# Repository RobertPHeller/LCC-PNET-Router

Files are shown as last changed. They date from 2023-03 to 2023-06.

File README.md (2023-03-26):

# LCC-PNET-Router

This is a "router" between a LCC network and a Pricom Lighting PNET network.
It translates between LCC event reports and PNET Trigger, Control, and Dimmer 
messages.  The PCB contains CAN transceivers for the two CAN IFs on a 
PocketBeagle, with one wired to LCC network connectors (RJ45s) and the other 
wired for PNET (RJ12 6-6).  The "firmware" compiles and runs on a 32-bit ARM
Linux SBC (tested on a Beagle Bone using GridConnect over Tcp/Ip for the LCC
network and the Virtual CAN driver (vcan) for the PNET network.

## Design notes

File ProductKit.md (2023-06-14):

This is a "router" between a LCC network and a Pricom Lighting PNET network.
It translates between LCC event reports and PNET Trigger, Control, and Dimmer 
messages.  The PCB contains CAN transceivers for the two CAN IFs on a 
PocketBeagle, with one wired to LCC network connectors (RJ45s) and the other 
wired for PNET (RJ12 6-6).  Both networks have data activity LEDs and an 
on-board termination jumper header.  And the LCC network has power injection
and tap screw terminals.

This kit contains:

- The PCB with all of the SMD parts assembled.
- The through-hole parts (to be soldered on by the end user):
    - 2 RJ45 8-8 connectors
    - 2 RJ12 6-6 connectors
    - 2 2.54mm (.1") screw terminal blocks
    - 2 2x18 2.54mm (.1") pitch socket headers
    - 1 2x40 2.54mm (.1") pitch "breakaway" pin headers
    - 1 USB A connector
- 1 MicroSD card containing the firmware image
- 4 2.54mm (.1") shorting jumpers (for the termination headers)
 
Not included: a [PocketBeagle](https://duckduckgo.com/?t=ffab&q=pocketBeagle&iax=shopping&ia=shopping).

The included firmware is built to provide 32 each of PNET controls, triggers,
and dimmers.  Each PNET message item maps two LCC events to the PNET message,
one eventid is consumed to generate the PNET message and the other is produced
when the matching PNET message is seen on the PNET network.  The PNET message
processing is configured using the LCC CDI configuration (eg with JMRI's 
PanelPro or DWS's OpenLCB program).

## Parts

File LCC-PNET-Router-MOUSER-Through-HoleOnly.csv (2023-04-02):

Item | Qty | Reference(s) | Value | LibPart | Footprint | Datasheet | Mouser Part Number
1 | 1 | J101 | USB_A | conn:USB_A | USB-A-Upright:USB-A-UPRIGHT |  | 710-614004184726
2 | 2 | J202, J203 | RJ45 | conn:RJ45 | RJ45-8N-S:RJ45_8N-S |  | 710-615008144221
3 | 2 | J302, J303 | PNET | conn:RJ12 | RJ12Molex:95501-2661 |  | 538-95501-2661
4 | 2 | P1, P2 | POCKETBEAGLE-P2 | pocketbeagle:POCKETBEAGLE-P2 | Socket_Strips:Socket_Strip_Straight_2x18_Pitch2.54mm |  | 517-929975-01-18-RK
5 | 1 |  | Pin Headers |  | Socket_Strips:Pin_Strip_Straight_2x40_Pitch2.54mm |  | 710-61308021121
6 | 2 | T201, T202 | LCC Power In/Out | conn:Screw_Terminal_01x02 | Connectors_Terminal_Blocks:TerminalBlock_Pheonix_MPT-2.54mm_2pol |  | 651-1703144

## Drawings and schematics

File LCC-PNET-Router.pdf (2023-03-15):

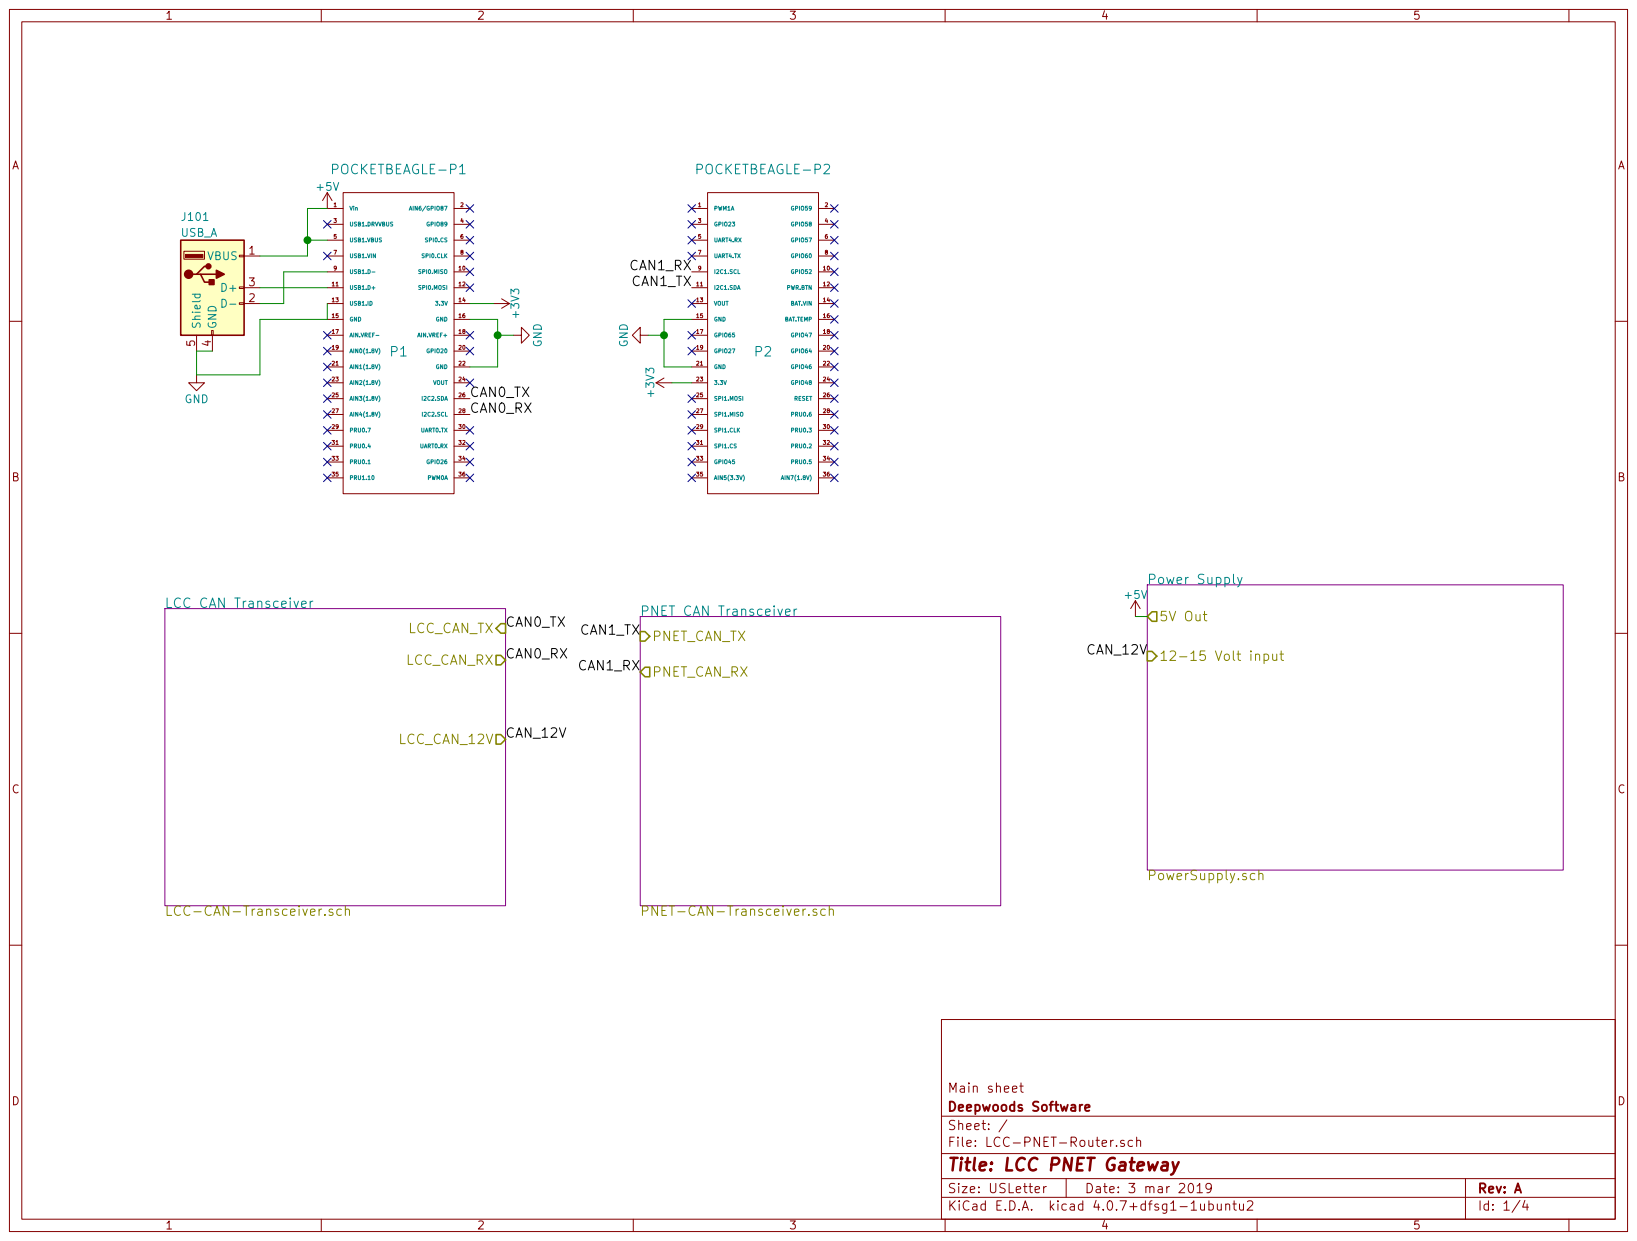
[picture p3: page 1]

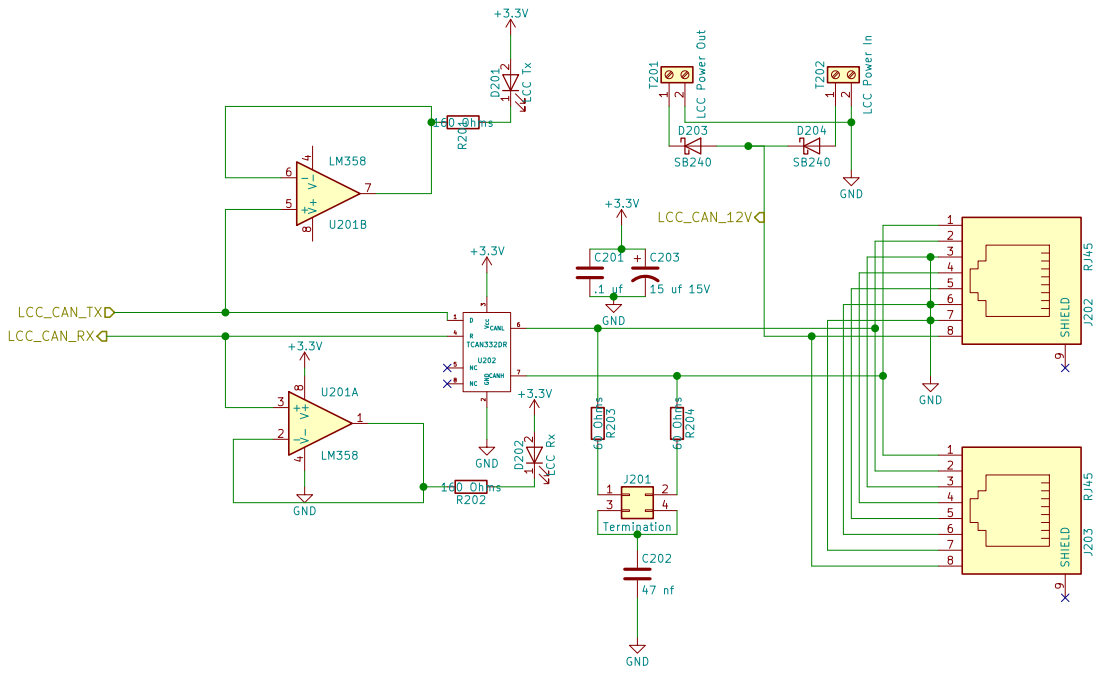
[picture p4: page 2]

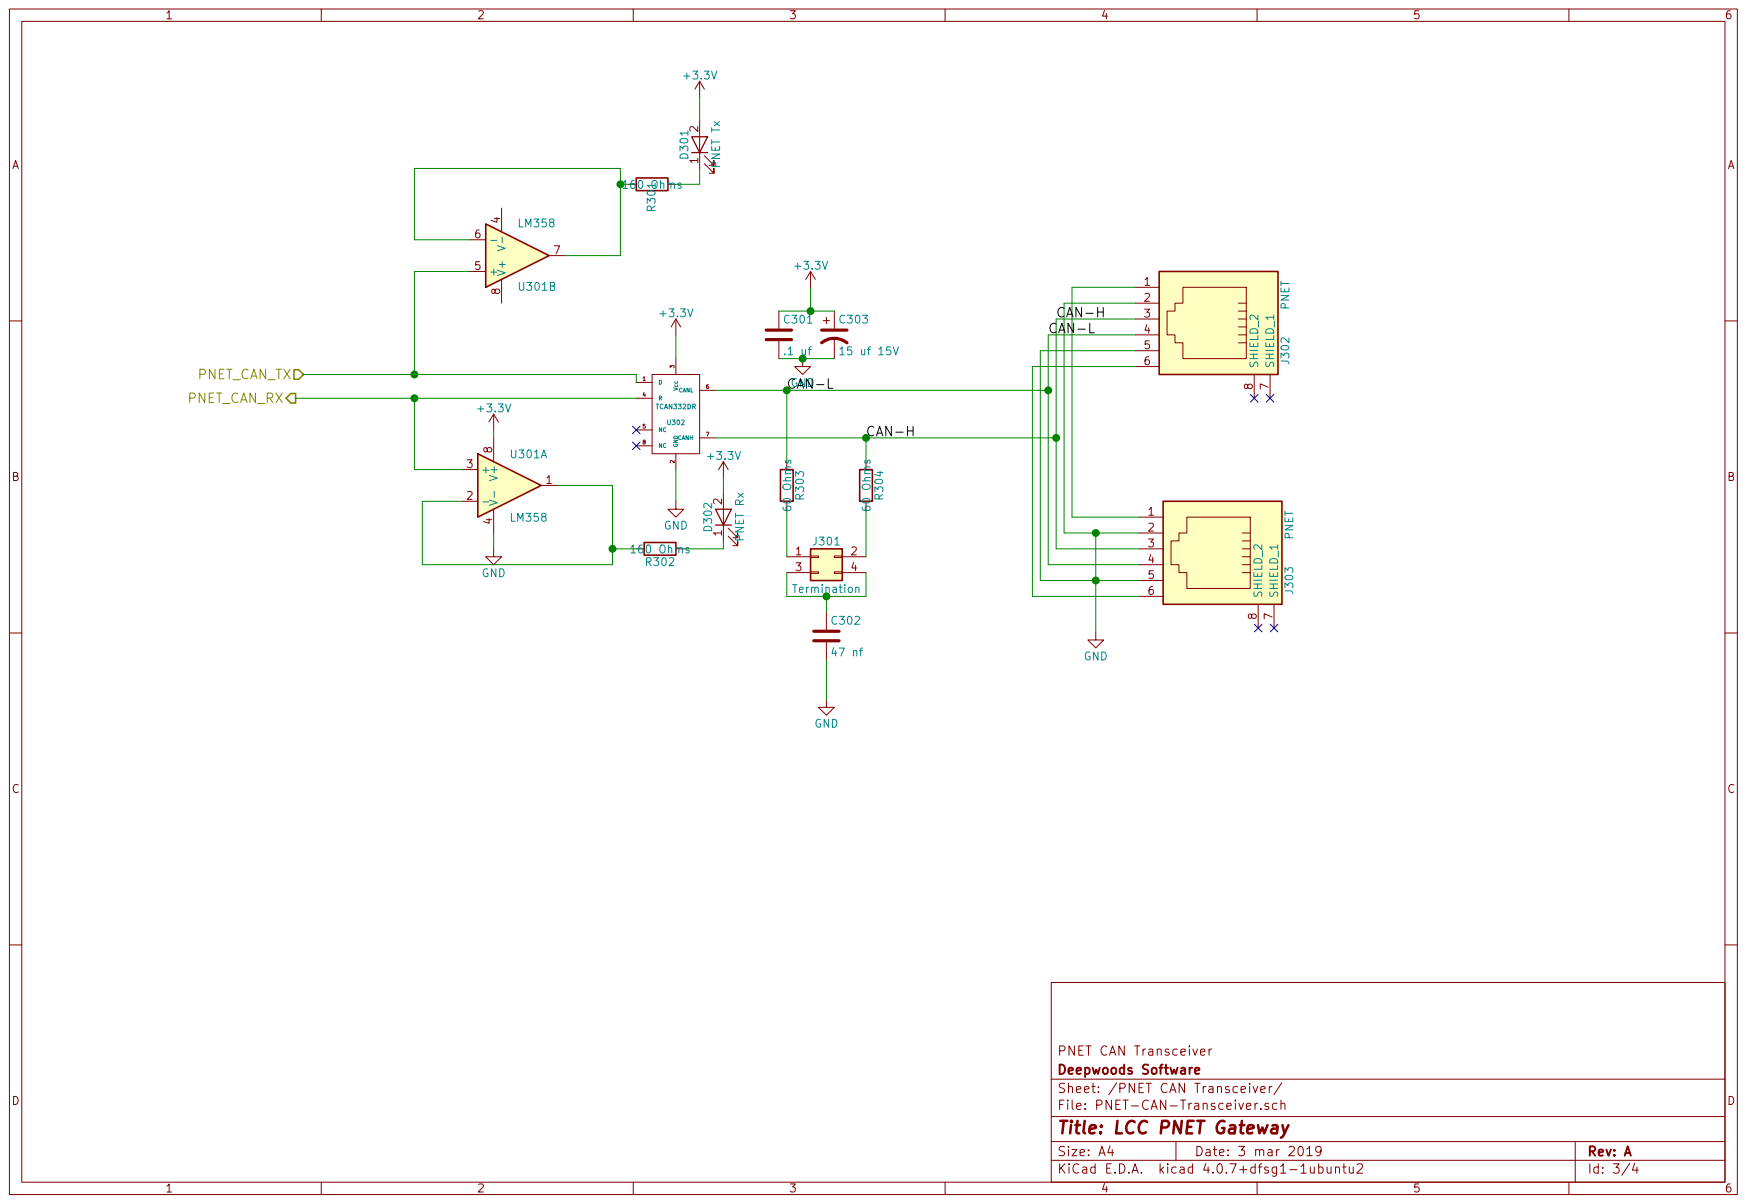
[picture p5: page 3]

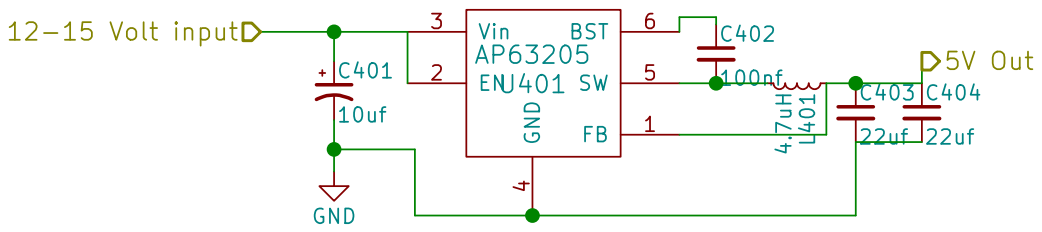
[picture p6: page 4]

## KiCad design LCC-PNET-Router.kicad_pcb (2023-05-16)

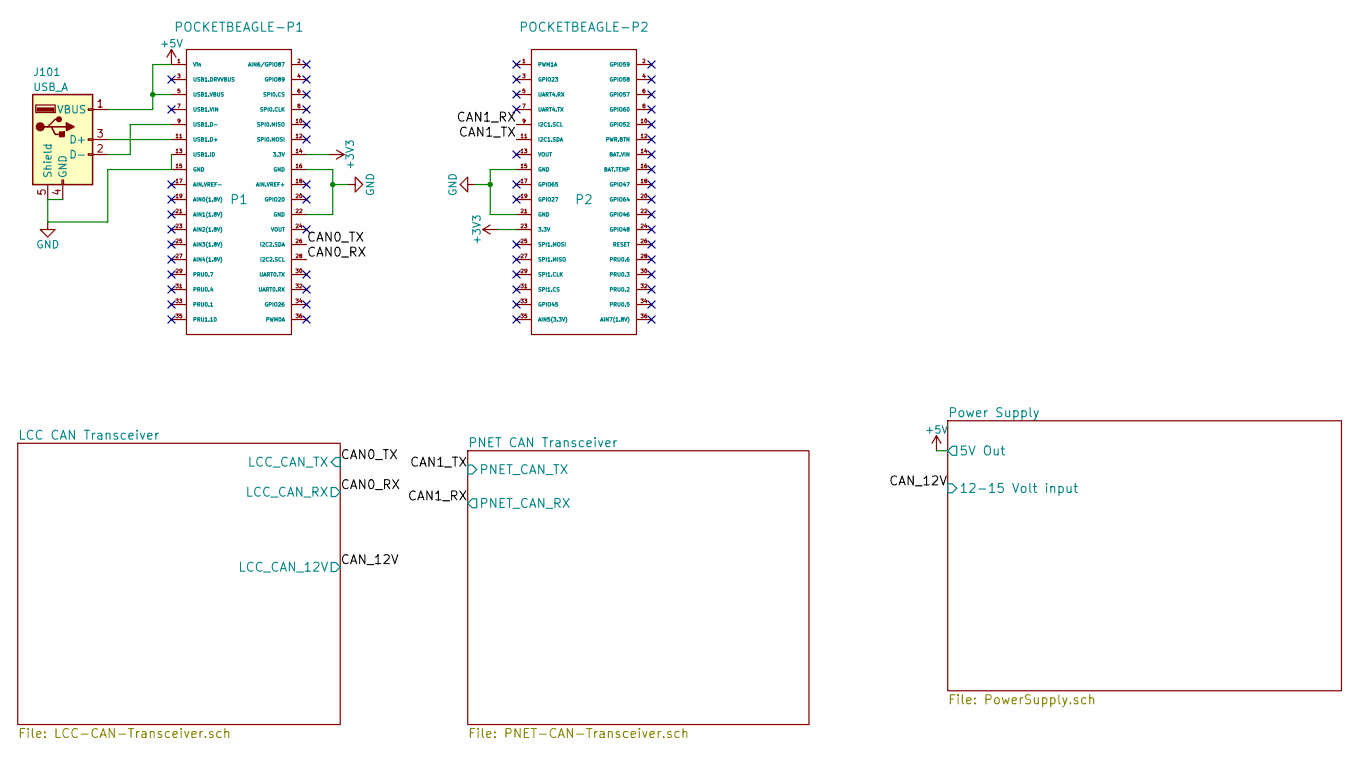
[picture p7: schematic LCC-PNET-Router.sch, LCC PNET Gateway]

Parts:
J101: USB_A; USB-A-UPRIGHT; Mouser Part Number 710-614004184726
P1: POCKETBEAGLE-P1; Socket_Strip_Straight_2x18_Pitch2.54mm; Mouser Part Number 517-929975-01-18-RK
P2: POCKETBEAGLE-P2; Socket_Strip_Straight_2x18_Pitch2.54mm; Mouser Part Number 517-929975-01-18-RK

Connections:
+5V: J101.1 (VBUS), P1.1 (Vin), P1.5 (USB1.VBUS); also elsewhere on the board
/CAN0_RX: P1.28 (I2C2.SCL); also elsewhere on the board
/CAN0_TX: P1.26 (I2C2.SDA); also elsewhere on the board
/CAN1_RX: P2.9 (I2C1.SCL); also elsewhere on the board
/CAN1_TX: P2.11 (I2C1.SDA); also elsewhere on the board
GND: J101.4 (GND), J101.5 (Shield), P1.13 (USB1.ID), P1.15 (GND), P1.16 (GND), P1.22 (GND), P2.15 (GND), P2.21 (GND); also elsewhere on the board
unnamed: J101.2 (D-), P1.9 (USB1.D-)
unnamed: J101.3 (D+), P1.11 (USB1.D+)

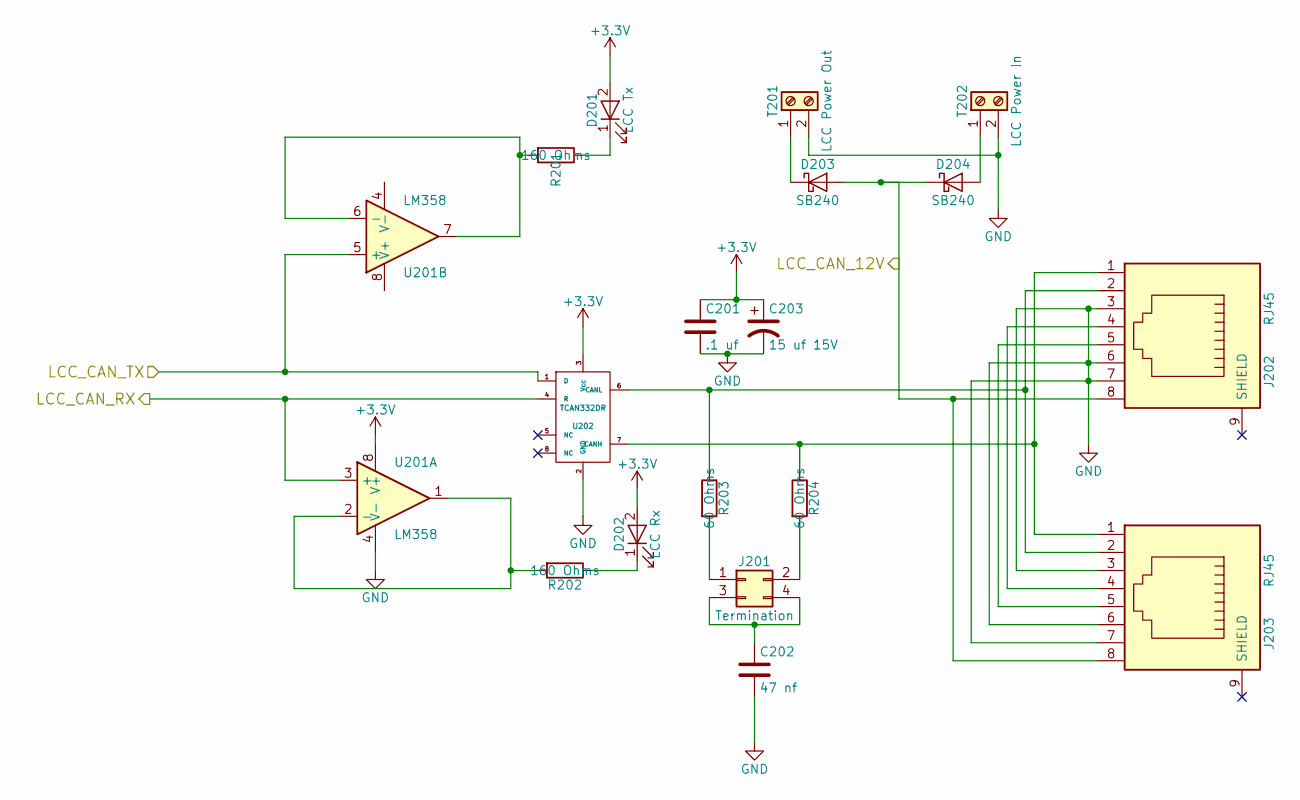
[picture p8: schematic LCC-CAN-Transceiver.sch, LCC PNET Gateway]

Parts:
C201: .1 uf; C_0603; Mouser Part Number 603-CC603KPX7R9BB104
C202: 47 nf; C_0603; Mouser Part Number 963-GMK107BJ473KAHT
C203: 15 uf 15V; CP_Elec_4x5.8; Mouser Part Number 647-UUD1C150MCL
D201: LCC Tx; LED_0603; Mouser Part Number 710-150060SS75000
D202: LCC Rx; LED_0603; Mouser Part Number 710-150060YS75000
D203, D204: SB240; D_PowerDI-123; Mouser Part Number 621-DFLS240-7
J201: Termination; Pin_Header_Straight_2x02_Pitch2.54mm; Mouser Part Number 649-1012938190402BLF
J202, J203: RJ45; RJ45_8N-S; Mouser Part Number 710-615008144221
R201, R202: 160 Ohms; R_0603; Mouser Part Number 603-AC0603JR-07160RL
R203, R204: 60 Ohms; R_1206; Mouser Part Number 71-CRCW120660R0KNAIF
T201: LCC Power Out; TerminalBlock_Pheonix_MPT-2.54mm_2pol; Mouser Part Number 651-1725656
T202: LCC Power In; TerminalBlock_Pheonix_MPT-2.54mm_2pol; Mouser Part Number 651-1725656
U201: LM358; SOIC-8_3.9x4.9mm_Pitch1.27mm; Mouser Part Number 595-LM358DR
U202: TCAN332DR; SOIC-8_3.9x4.9mm_Pitch1.27mm; Mouser Part Number 595-TCAN332DR

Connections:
/CAN0_RX: U201.3 (+), U202.4 (R); also elsewhere on the board
/CAN0_TX: U201.5 (+), U202.1 (D); also elsewhere on the board
/CAN_12V: D203.2 (A), D204.1 (K), J202.8, J203.8; also elsewhere on the board
GND: C201.2, C202.2, C203.2, J202.3, J202.6, J202.7, J203.3, J203.6, J203.7, T201.2, T202.2, U201.4 (V-), U202.2 (GND); also elsewhere on the board
unnamed: C202.1, J201.3, J201.4
unnamed: D201.1 (K), R201.1
unnamed: D202.1 (K), R202.1
unnamed: D203.1 (K), T201.1
unnamed: D204.2 (A), T202.1
unnamed: J201.1, R203.2
unnamed: J201.2, R204.2
unnamed: J202.1, J203.1, R204.1, U202.7 (CANH)
unnamed: J202.2, J203.2, R203.1, U202.6 (CANL)
unnamed: J202.4, J203.4
unnamed: J202.5, J203.5
unnamed: R201.2, U201.6 (-), U201.7
unnamed: R202.2, U201.1, U201.2 (-)

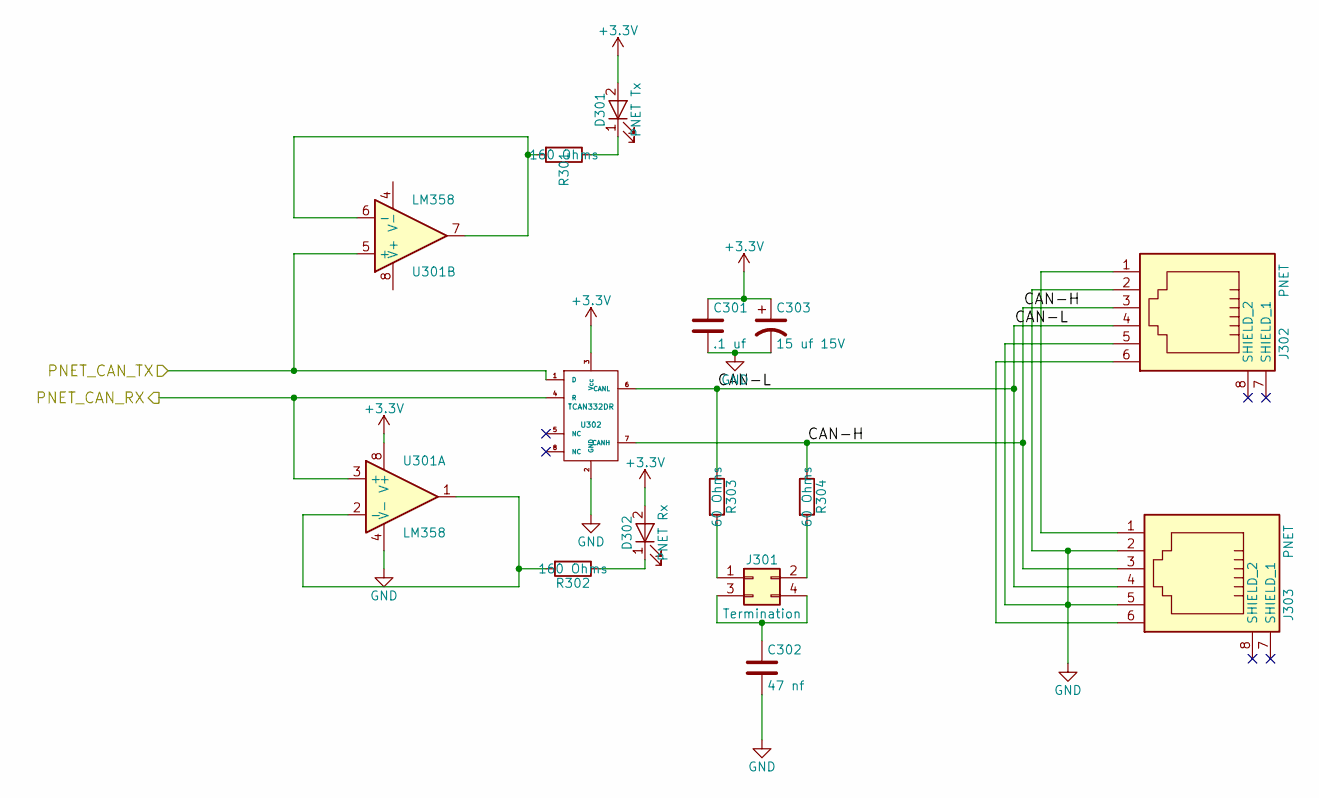
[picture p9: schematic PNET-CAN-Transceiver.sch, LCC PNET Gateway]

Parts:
C301: .1 uf; C_0603; Mouser Part Number 603-CC603KPX7R9BB104
C302: 47 nf; C_0603; Mouser Part Number 963-GMK107BJ473KAHT
C303: 15 uf 15V; CP_Elec_4x5.8; Mouser Part Number 647-UUD1C150MCL
D301: PNET Tx; LED_0603; Mouser Part Number 710-150060SS75000
D302: PNET Rx; LED_0603; Mouser Part Number 710-150060YS75000
J301: Termination; Pin_Header_Straight_2x02_Pitch2.54mm; Mouser Part Number 649-1012938190402BLF
J302, J303: PNET; 95501-2661; Mouser Part Number 538-95501-2661
R301, R302: 160 Ohms; R_0603; Mouser Part Number 603-AC0603JR-07160RL
R303, R304: 60 Ohms; R_1206; Mouser Part Number 71-CRCW120660R0KNAIF
U301: LM358; SOIC-8_3.9x4.9mm_Pitch1.27mm; Mouser Part Number 595-LM358DR
U302: TCAN332DR; SOIC-8_3.9x4.9mm_Pitch1.27mm; Mouser Part Number 595-TCAN332DR

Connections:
/CAN1_RX: U301.3 (+), U302.4 (R); also elsewhere on the board
/CAN1_TX: U301.5 (+), U302.1 (D); also elsewhere on the board
/PNET CAN Transceiver/CAN-H: J302.3, J303.3, R304.1, U302.7 (CANH)
/PNET CAN Transceiver/CAN-L: J302.4, J303.4, R303.1, U302.6 (CANL)
GND: C301.2, C302.2, C303.2, J302.2, J302.5, J303.2, J303.5, U301.4 (V-), U302.2 (GND); also elsewhere on the board
unnamed: C302.1, J301.3, J301.4
unnamed: D301.1 (K), R301.1
unnamed: D302.1 (K), R302.1
unnamed: J301.1, R303.2
unnamed: J301.2, R304.2
unnamed: J302.1, J303.1
unnamed: J302.6, J303.6
unnamed: R301.2, U301.6 (-), U301.7
unnamed: R302.2, U301.1, U301.2 (-)

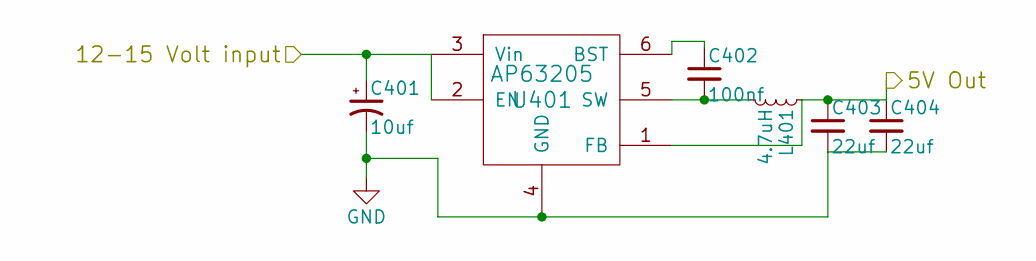
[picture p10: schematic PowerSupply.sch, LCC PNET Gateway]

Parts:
C401: 10uf; CP_Elec_5x5.3; Mouser Part Number 710-865230542002
C402: 100nf; C_0603; Mouser Part Number 710-885012206020
C403, C404: 22uf; C_0603; Mouser Part Number 81-GRM188R60G226ME0J
L401: 4.7uH; L_7.3x7.3_H4.5; Mouser Part Number 81-B1047AS-4R7NP3
U401: AP63205; TSOT-23-6_MK06A; Mouser Part Number 621-AP63205WU-7

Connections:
+5V: C403.1, C404.1, L401.1, U401.1 (FB); also elsewhere on the board
/CAN_12V: C401.1, U401.2 (EN), U401.3 (Vin); also elsewhere on the board
GND: C401.2, C403.2, C404.2, U401.4 (GND); also elsewhere on the board
unnamed: C402.1, U401.6 (BST)
unnamed: C402.2, L401.2, U401.5 (SW)

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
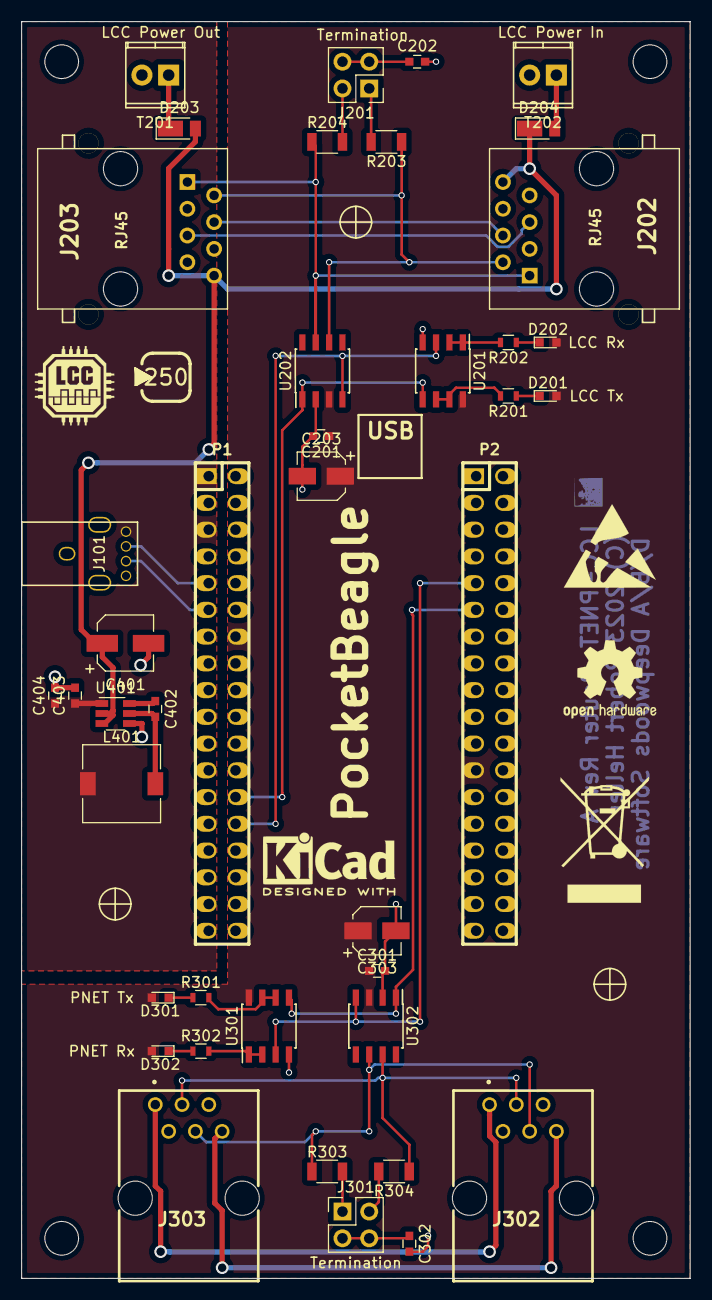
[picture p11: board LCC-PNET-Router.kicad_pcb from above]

Board: 2 copper layers, 63.5 x 119.4 mm, 41 parts (0 on the bottom side), 36 nets.

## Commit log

2023-01-12 Start on LCC <=> PNET router.
    [LCC-CAN-Transceiver.sch, LCC-PNET-Router.kicad_pcb, LCC-PNET-Router.sch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]
2023-01-12 Start on PCB layout.
    [LCC-PNET-Router.kicad_pcb, LCC-PNET-Router.sch, PowerSupply.sch]
2023-03-15 Completed initial HW design.
    [LCC-CAN-Transceiver.sch, LCC-PNET-Router.kicad_pcb, LCC-PNET-Router.sch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]
2023-03-15 Add Schematic PDF.
    [LCC-CAN-Transceiver.sch, LCC-PNET-Router.sch, PNET-CAN-Transceiver.sch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]
2023-03-15 Correct for CAN Polarity on the PNET connectors.
    [LCC-PNET-Router.kicad_pcb, PNET-CAN-Transceiver.sch]
2023-03-18 Refactor PNETTriggerService using an iterator flow.
2023-03-22 Update RJ12 Jacks.
    [LCC-PNET-Router.kicad_pcb, PNET-CAN-Transceiver.sch]
2023-03-22 Complete 3D and final touches on PCB.
    [LCC-PNET-Router.kicad_pcb]
2023-03-23 Finalize Parts Lists, generate Gerbers, etc.
    [LCC-PNET-Router-MOUSER-Through-HoleOnly.csv, LCC-PNET-Router.kicad_pcb, LCC-PNET-Router.sch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]
2023-03-29 Last minute update: dims and fids.
    [LCC-PNET-Router.kicad_pcb]
2023-04-02 Add missing parts to Mouser BOM.
    [LCC-PNET-Router-MOUSER-Through-HoleOnly.csv]
2023-05-16 Update PCB: fix errors.
    [LCC-PNET-Router.kicad_pcb]
2023-06-10 Add in new kicad files.
2023-07-02 Add Kit Insert.
2023-07-10 Add booklet insert generation.

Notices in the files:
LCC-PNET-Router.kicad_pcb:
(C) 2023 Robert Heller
